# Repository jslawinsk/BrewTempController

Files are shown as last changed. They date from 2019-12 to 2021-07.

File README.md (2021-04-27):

# Brewery Temperature Controller
Brewery Temperature Controller

Refer to the Wiki for details: https://github.com/jslawinsk/BrewTempController/wiki

#Arduino Shield Design

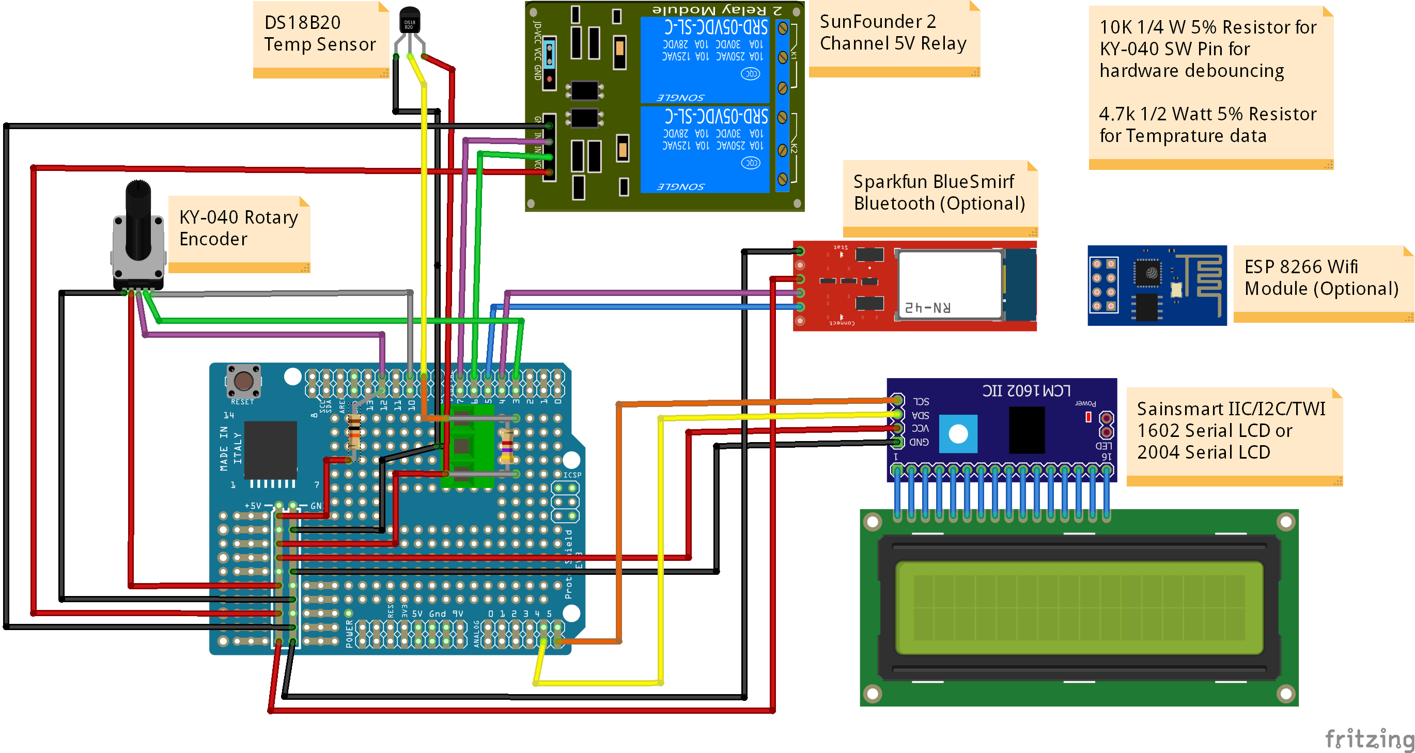
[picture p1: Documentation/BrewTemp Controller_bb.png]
Auduino Shield Diagram


In the below diagram the encapsulated green boxes indicates this components architecture placement.

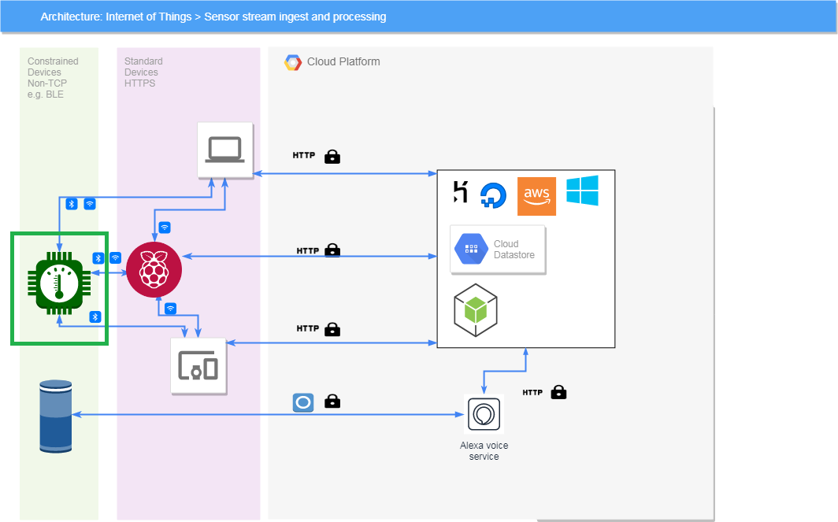
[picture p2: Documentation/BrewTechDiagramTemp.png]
Architecture Diagram
 

Tools Used:
- Arduino Studio
- Fritzing 
- Draw.io

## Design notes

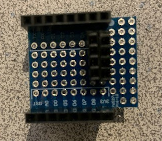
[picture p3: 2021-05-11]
Documentation/D1Prototype/D1MiniShield1.png

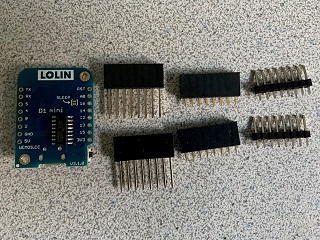
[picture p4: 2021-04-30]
Documentation/D1Prototype/D1Mini.png

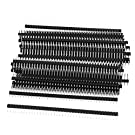
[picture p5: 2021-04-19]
Documentation/BrewTempControllerList - Amazon.com_files/511gPovqycL.jpg

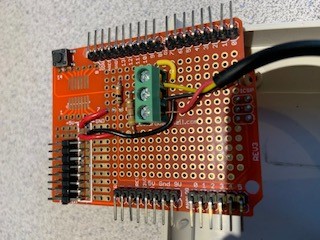
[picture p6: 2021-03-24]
Documentation/ProtoType/Protype13.png

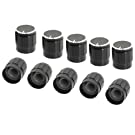
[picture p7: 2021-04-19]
Documentation/BrewTempControllerList - Amazon.com_files/41CCy1pXQL.jpg

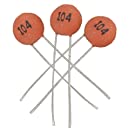
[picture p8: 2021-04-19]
Documentation/BrewTempControllerList - Amazon.com_files/41uLexGseAL.jpg

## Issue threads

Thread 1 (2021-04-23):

Celsius issue

kiks46, 2021-04-23:
Hi,
When I change the temperature to celsius it doesn't measure it, on the main screen says -17, and it is impossible to change target temp.

Thanks

jslawinsk, 2021-04-26:
Interesting, I'll review the code,

jslawinsk, 2021-04-26:
Just updated the code to address the Celsius issue. The code was updated to use a formula instead of the DallasTemperature::toCelsius method. The rotary encoder also updated to detect the correct direction between Wemos d1 and Arduino Uno.

Thank you for spotting the issue, please try the latest version.

kiks46, 2021-04-26:
Cheers man, your project is awesome! I'm soldering the board to fit it all in a box... once it's done I will update it and I will let you know...
Thanks!

Closed 2021-04-26.

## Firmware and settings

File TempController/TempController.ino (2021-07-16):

#include <OneWire.h>
#include <DallasTemperature.h>

// #define DEBUG 1
//
// The following are defined for components which are installed
//
#define BLUETOOTH_ENABLED 1
#define ROTARY_ENABLED 1
#define RELAY_ENABLED 1
// #define WIFI_ENABLED 1
#define LCD_20X4 1    // Comment this line if using 16 x 2 LCD
//
// Define the following if using a Lolin D1 Mini, comment the following line for Arduino
//
// #define D1_MINI 1

float currentTemprature;  // Current Temprature store in farenheight

#ifdef D1_MINI
  int RelayHeat = D7;
  int RelayCool = D8;
#else
  int RelayHeat = 6;
  int RelayCool = 7;
#endif

const int RELAY_NONE = 0;
const int RELAY_HEAT = 1;
const int RELAY_COOL = 2;
const int RELAY_OVERRIDE_HEAT = 3;
const int RELAY_OVERRIDE_COOL = 4;
int RelayStatus = RELAY_NONE;

const int CONTROL_AUTO = 0;
const int CONTROL_HEAT = 1;
const int CONTROL_COOL = 2;
int controlMode = CONTROL_AUTO;

boolean controlCommandReceived = false;

const int SCREENMODE_DISPLAYTEMP = 1;
const int SCREENMODE_SETUP = 2;
const int SCREENMODE_SCREEN_SAVER = 3;
int screenMode = SCREENMODE_DISPLAYTEMP;

const int DISPLAYMODE_MAIN    = 0;
const int DISPLAYMODE_TARGET  = 1;
const int DISPLAYMODE_MINMAX  = 2;
int currentDisplayMode = DISPLAYMODE_MAIN;

unsigned long screenTime;

const int UNIT_FARENHEIGHT = 1;
const int UNIT_CELSIUS = 2;
int unit =  UNIT_FARENHEIGHT;

float deviation = 1.0;
float calibration= 0.0;
int targetTemp = 70;
unsigned long tempratureTimer;

//temp sensor defines

// Data wire is plugged into port 2 on the Arduino

#ifdef D1_MINI
  #define ONE_WIRE_BUS D4
#else
  #define ONE_WIRE_BUS 9
#endif
#define TEMPERATURE_PRECISION 9 // Lower resolution
#define TEMPERATURE_MINIMUM 0
#define TEMPERATURE_MAXIMUM 275

// Setup a oneWire instance to communicate with any OneWire devices (not just Maxim/Dallas temperature ICs)
OneWire oneWire(ONE_WIRE_BUS);

// Pass our oneWire reference to Dallas Temperature. 
DallasTemperature sensors(&oneWire);

int numberOfDevices; // Number of temperature devices found

float _minTemp = 1024.0;
float _maxTemp = -100.0;

DeviceAddress tempDeviceAddress; // We'll use this variable to store a found device address

void setup(void)
{
  displayLogo();
  
  //setup temp sensor
  // start serial port
  Serial.begin(9600);
  Serial.println("Dallas Temperature IC Control Setup");

  // Start up the library
  sensors.begin();
  
  // Grab a count of devices on the wire
  numberOfDevices = sensors.getDeviceCount();
  
  // locate devices on the bus
  Serial.print("Locating devices...");
  
  Serial.print("Found ");
  Serial.print(numberOfDevices, DEC);
  Serial.println(" devices.");

  // report parasite power requirements
  Serial.print("Parasite power is: "); 
  if (sensors.isParasitePowerMode()) Serial.println("ON");
  else Serial.println("OFF");
  
  // Loop through each device, print out address
  for(int i=0;i<numberOfDevices; i++)
  {
    // Search the wire for address
    if(sensors.getAddress(tempDeviceAddress, i))
    {
      Serial.print("Found device ");
      Serial.print(i, DEC);
      Serial.print(" with address: ");
      printAddress(tempDeviceAddress);
      Serial.println();
    
      Serial.println("Setting resolution to ");
      Serial.println();
      Serial.println(TEMPERATURE_PRECISION, DEC);
      Serial.println();
      // set the resolution to TEMPERATURE_PRECISION bit (Each Dallas/Maxim device is capable of several different resolutions)
      sensors.setResolution(tempDeviceAddress, TEMPERATURE_PRECISION);
      delay(500);
      Serial.print("Resolution actually set to: ");
      Serial.print(sensors.getResolution(tempDeviceAddress), DEC); 
      delay(500);
      Serial.println();
      //break;
    }else{
      Serial.print("Found ghost device at ");
      Serial.print(i, DEC);
      Serial.print(" but could not detect address. Check power and cabling");
    }    
  }

  Serial.begin(9600);
  #ifdef ROTARY_ENABLED
  Serial.println();
  Serial.print( "Setting up Rotary Encoder" );
  //rotary encoder setup

  rotarySetup();
  #endif
  Serial.begin (9600);

  //
  //  Releay Switch Setup
  //
  #ifdef RELAY_ENABLED
  pinMode(RelayHeat, OUTPUT); //Set Pin12 as output 
  pinMode(RelayCool, OUTPUT); //Set Pin12 as output 
  digitalWrite(RelayHeat, HIGH); //Turn off relay 
  digitalWrite(RelayCool, HIGH); //Turn off relay 
  #endif
  RelayStatus = RELAY_NONE;

  #ifdef BLUETOOTH_ENABLED  
  bluetoothSetup();
  #endif
  
  relaySetup();

  #ifdef WIFI_ENABLED
  wifiSetup();
  #endif
  
  screenTime = millis();
  tempratureTimer = millis();

  delay( 4000 );
  lcdclear();
  setTempratureTemplate();  
}


void loop(void)
{ 
  if(screenMode != SCREENMODE_SETUP ){
    temperatureInterface();
    relayControl();
    #ifdef BLUETOOTH_ENABLED
      bluetoothInterface();
    #endif
  }
  #ifdef ROTARY_ENABLED
  rotary();
  #endif

  #ifdef WIFI_ENABLED
  wifiLoop();
  #endif

}



// function to print the temperature for a device
void printTemperature( )
{
    if(screenMode == SCREENMODE_DISPLAYTEMP ){
      #ifdef LCD_20X4
        lcdsetCursor( 13, 0 );         
      #else
        lcdsetCursor( 5, 0 );
      #endif
      lcdprint( getDisplayTemperature( currentTemprature ) );           // update the display with a new number
  
      //
      //  Screensaver code
      //
      unsigned long delayTime = 60000 * 15;
      unsigned long currentTime = millis();
      if( screenTime + delayTime < currentTime ){
        screenMode = SCREENMODE_SCREEN_SAVER;
        lcdsetBacklightLOW();
      }
    }
}

String getDisplayTemperature( float tempF ){
    String strTemp = "";
    if(unit == UNIT_FARENHEIGHT)
    {
      strTemp = String(tempF);
      strTemp = strTemp.substring( 0, 4 );
      strTemp = strTemp + " \xDF";
      strTemp = strTemp + "F";
    }
    else{
      // float tempF = DallasTemperature::toCelsius( tempF );
      float tempC = ( tempF - 32 ) * 0.5556;;
      strTemp = String( tempC );
      strTemp = strTemp.substring( 0, 4 );
      strTemp = strTemp + " \xDF";
      strTemp = strTemp + "C";
    }
    return strTemp;
}

String getDisplayTemperatureBasic( float tempF ){
    String strTemp = "";
    if(unit == UNIT_FARENHEIGHT)
    {
      strTemp = String(tempF);
    }
    else{
      // float tempF = DallasTemperature::toCelsius( tempF );
      float tempC = ( tempF - 32 ) * 0.5556;;
      strTemp = String( tempC );
    }
    strTemp = strTemp.substring( 0, 4 );
    return strTemp;
}


float getDisplayTemperatureNum( float tempF ){
    float nTemp = tempF;
    if(unit == UNIT_CELSIUS)
    {
      // nTemp = DallasTemperature::toCelsius(tempF);
      nTemp = (tempF-32) * 0.5556;
    }
    return nTemp;
}

//
//  Get Temprature Evry 1 Sec and Display
//
void temperatureInterface()
{
  // call sensors.requestTemperatures() to issue a global temperature 
  // request to all devices on the bus

  unsigned long currentTime = millis();
  if( tempratureTimer + 1000 < currentTime ){

    sensors.requestTemperatures(); // Send the command to get temperatures
    // Loop through each device, print out temperature data
    for(int i=0;i<numberOfDevices; i++)
    {
      // Search the wire for address
      if(sensors.getAddress(tempDeviceAddress, i))
      {
        // Output the device ID
        //    Serial.print("Temperature for device: ");
        //    Serial.println(i,DEC);
        //float tempC = sensors.getTempC(tempDeviceAddress);
        //currentTemprature = DallasTemperature::toFahrenheit(tempC);
        currentTemprature = sensors.getTempF(tempDeviceAddress);
        currentTemprature = currentTemprature + calibration;
        if( currentTemprature >= TEMPERATURE_MINIMUM && currentTemprature <= TEMPERATURE_MAXIMUM )
        {
          if(currentTemprature >= _maxTemp)
          {
            _maxTemp = currentTemprature;
            if( currentDisplayMode == DISPLAYMODE_MINMAX ){
              #ifdef LCD_20X4
                lcdsetCursor ( 13, 1 );            // go to the 2nd row
              #else
                lcdsetCursor ( 11, 1 );            // go to the 2nd row
              #endif
            }
            #ifdef LCD_20X4
              if( currentDisplayMode == DISPLAYMODE_MAIN ){
                lcdsetCursor ( 13, 2 );
              } else if( currentDisplayMode == DISPLAYMODE_TARGET ){
                lcdsetCursor ( 13, 3 );
              }
            #endif
            lcdprint( getDisplayTemperatureBasic( _maxTemp ) );              
          }
          if(currentTemprature <= _minTemp)
          {
            _minTemp = currentTemprature;
            if( currentDisplayMode == DISPLAYMODE_MINMAX ){
              #ifdef LCD_20X4
                lcdsetCursor ( 4, 1 );            // go to the 2nd row
              #else
                lcdsetCursor ( 3, 1 );            // go to the 2nd row
              #endif
            }
            #ifdef LCD_20X4
              if( currentDisplayMode == DISPLAYMODE_MAIN ){
                lcdsetCursor ( 4, 2 );
              } else if( currentDisplayMode == DISPLAYMODE_TARGET ){
                lcdsetCursor ( 4, 3 );
              }
            #endif
            lcdprint( getDisplayTemperatureBasic( _minTemp ) );
          }
        }
    }
    // It responds almost immediately. Let's print out the data
    printTemperature( ); // Use a simple function to print out the data
   } 
    //else ghost device! Check your power requirements and cabling
  }
}

// function to print a device address
void printAddress(DeviceAddress deviceAddress)
{
  for (uint8_t i = 0; i < 8; i++)
  {
    if (deviceAddress[i] < 16) Serial.print("0");
    Serial.print(deviceAddress[i], HEX);
  }
}

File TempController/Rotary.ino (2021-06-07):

int pinAstateCurrent = LOW;                // Current state of Pin A
int pinAStateLast = pinAstateCurrent;      // Last read value of Pin A

#ifdef D1_MINI
  int pinB = D0;        // Connected to DT on KY-040
  int pinA = D5;        // Connected to CLK on KY-040
  int switchPin = D6;   // Connected to SW on KY-040
#else
  int pinB = 3;        // Connected to DT on KY-040
  int pinA = 10;       // Connected to CLK on KY-040
  int switchPin = 12;  // Connected to SW on KY-040
#endif

int switchState = HIGH; // button value

int rotationValue = 0;

const int EDIT_START = 0;
const int EDIT_NONE = 1;
const int EDIT_ACTIVE = 2;
int editMode = EDIT_START;

const int SETUP_ITEM_TEMP = 1;
const int SETUP_ITEM_UNIT = 2;
const int SETUP_ITEM_DEVIATION = 3;
const int SETUP_ITEM_CONTROL = 4;
const int SETUP_ITEM_CALIBRATION = 5;
const int SETUP_ITEM_DONE = 6;
int setupItem = SETUP_ITEM_TEMP;

void rotarySetup(){

  pinMode ( switchPin, INPUT_PULLUP );
  pinMode ( pinA, INPUT );
  pinMode ( pinB, INPUT );
   /* Read Pin A
   Whatever state it's in will reflect the last position   
   */
#ifdef D1_MINI
  attachInterrupt(digitalPinToInterrupt( pinA), rotaryIsr, CHANGE);   // interrupt 0 is always connected to pin 2 on Arduino UNO
#else
  attachInterrupt(digitalPinToInterrupt( pinB), rotaryIsr, CHANGE);   // interrupt 0 is always connected to pin 2 on Arduino UNO
  pinAStateLast = digitalRead( pinA );   
#endif
}

void rotary(){
  //
  //  Handle Button Press
  //
  switchState = digitalRead( switchPin );    // Read the digital value of the switch (LOW/HIGH)
  // If the switch is pressed (LOW), button pressed
  if( switchState == LOW ) {
    delay( 100 );
    while( !(digitalRead( switchPin )) );
    #ifdef DEBUG
      Serial.println( "Button Pressed" );
    #endif
    
    if( screenMode == SCREENMODE_SCREEN_SAVER ){
      screenMode = SCREENMODE_DISPLAYTEMP;
      lcdsetBacklightHIGH(); // Turn on backlight, LOW for off
      screenTime = millis();
    }
    else if( screenMode != SCREENMODE_SETUP ){
      screenMode = SCREENMODE_SETUP;
      setupItem = SETUP_ITEM_TEMP;
      editMode = EDIT_START;
    }
    if(screenMode ==  SCREENMODE_SETUP && setupItem == SETUP_ITEM_TEMP && editMode == EDIT_START )
    {
      lcdclear();
      lcdsetCursor ( 0, 0 );            
      lcdprint("Target Temp"); 
      lcdsetCursor ( 0, 1 );
      lcdprint( getDisplayTemperature( targetTemp ) );     
    }
    if(screenMode == SCREENMODE_SETUP ){
      if (editMode == EDIT_START){
        editMode = EDIT_NONE;
      }
      else if (editMode == EDIT_NONE){
         editMode = EDIT_ACTIVE; 
      }
      else if (editMode == EDIT_ACTIVE){
         editMode = EDIT_NONE; 
      }
      if( setupItem == SETUP_ITEM_DONE ){
        screenMode = SCREENMODE_DISPLAYTEMP; 
        setTempratureTemplate();  
        screenTime = millis();      
      }
    }
  }

  if(screenMode == SCREENMODE_SETUP && rotationValue != 0 )
  {
    setSettings( );
  }
  else if ( screenMode != SCREENMODE_SETUP && screenMode != SCREENMODE_SCREEN_SAVER && rotationValue != 0 ){
    //
    //  Here we are checking screenMode != SCREENMODE_SETUP 
    //  because the ISR could be triggered between if and else
    //  this is to avoid gost display while in settings. If
    //  screenMode != SCREENMODE_SETUP is removed gost display appears while in settings (sometimes).
    //
    changeDisplay();
  }
  if( rotationValue != 0 ){
    rotationValue = 0;
    screenTime = millis(); 
    if( screenMode == SCREENMODE_SCREEN_SAVER ){
      screenMode = SCREENMODE_DISPLAYTEMP;
      lcdsetBacklightHIGH(); 
    }         
  }
}


#ifdef D1_MINI
ICACHE_RAM_ATTR void rotaryIsr(){
#else
void rotaryIsr(){
#endif
  // delay( 2 );
  pinAstateCurrent = digitalRead( pinA );
  if ((pinAStateLast == LOW) && (pinAstateCurrent == HIGH)) {  

    if (digitalRead( pinB ) == HIGH) {      // If Pin B is HIGH
      #ifdef D1_MINI
        rotationValue = -1;
      #else
        rotationValue = 1;
      #endif
      #ifdef DEBUG
      Serial.println("counterclockwise");             // Print on screen
      #endif
    } else {
      #ifdef D1_MINI
        rotationValue = 1;
      #else
        rotationValue = -1;
      #endif
      #ifdef DEBUG
      Serial.println("clockwise");            // Print on screen
      #endif
    }
  }
  pinAStateLast = pinAstateCurrent; // Store the latest read value in the currect state variable
}
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

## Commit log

2019-04-02 Initial Upload
    Arduino Temp Controller project
2019-04-17 Settings Fix and refactoring
    Fix for settings ghost display issue due to real-time consideration for interrupt service routine.
    [BlueTooth.ino, Rotary.ino, TempController.ino]
2019-12-15 Local Sync
    [BrewTemp Controller.fzz]
2019-12-15 Doc Update
    [BrewTemp Controller.fzz]
2020-01-01 Manual GIT Merger was required.
    Bluetooth: data sent as JSON object instead of just temperature value
    Relay Logic updated to have 1minute intervals to avoid flip flop when on
    temperature margin
    [BlueTooth.ino, Lcd.ino, Relay.ino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]
2020-01-09 Bluetooth: Added Command interface to change target temperature
    Changed base temperature type from celceus to farrenhieght
2020-01-11 Added ability to tur on Heat or Cool using Bluetooth command
2020-01-12 Added override of controler's heat and cool features using bluetooth commands
2021-03-12 Migrated LCD library from LiquidCrystal I2C library to hd44780 library for standard scetch library install. Removes offline library downloads.
2021-03-24 Prototype Images
2021-03-30 Prototype board update
    [BrewTemp Controller.fzz]
2021-04-13 Breadboad design and start of 20004 Display
    [Arduino Breaboard.fzz, BrewTemp Controller.fzz]
2021-04-14 Min and Max temperature values added to adjust for rotary encoder interference.
    [TempController.ino]
2021-04-16 Rotary Encoder Test manual merge to debug version 2
    [Arduino Breaboard.fzz]
2021-04-19 Rotery Encode Logic enhanced to address left rotation issue BlueTooth enable define added to disable bluetooth
    [BlueTooth.ino, DisplayTest.ino, Rotary.ino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]
2021-04-24 Updates for Lolin (Wemo) D1 Mini
    [LolinD1Mini Breaboard.fzz]
2021-04-25 Rotary SW Pin rewired for Lolin D1 Mini
    [LolinD1Mini Breaboard.fzz, LolinD1Mini Shield.fzz]
2021-04-26 Update for Celcius Issue #1.
    [LolinD1Mini Shield.fzz]
2021-04-30 D1 Mini Prototype
    [LolinD1Mini Shield.fzz]
2021-05-03 Fix forMin Max Display issue after adding degree symbol and unit type
    [Lcd.ino, TempController.ino]
2021-05-05 LCD Wiring Correction for D1 Mini
    [LolinD1Mini Breaboard.fzz, LolinD1Mini Shield.fzz]
2021-05-11 D1 Mini Protype Documentation
    [LolinD1Mini Breaboard.fzz]
2021-05-11 D1 Prototype docs
2021-06-01 D1 Mini Prototype with power
2021-06-07 Temperature Calibration and Calibration settings
2021-06-17 IMplemented setting temperature calibration setting with WiFi and Bluetooth
2021-06-18 Option to set Temperature Unit type configuration setting with WiFi and Bluetooth
2021-07-16 Implemented CORS to allow for WiFi Sensor testing and updates from the Sensor edit page of the brewery services application.
